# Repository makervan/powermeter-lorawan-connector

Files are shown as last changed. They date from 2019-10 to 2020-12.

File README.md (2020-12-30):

# DC Power Meter LoRaWAN Connector Node
LoRaWAN node to send data from the GC90/GC91 DC power meters via TTN. Based on an Arduino Pro Mini and the RFM95 LoRa module.

## Hardware
* Arduino Pro Mini 3.3V 8Mhz
* RFM95/96 LoRaWAN module
* [uFL socket](https://www.digikey.de/product-detail/en/linx-technologies-inc/CONUFL001-SMD-T/CONUFL001-SMD-TCT-ND/7427733) or edge mount SMA socket
* 2 BSS138 MOSFETs (Q1/Q2) and 2x 10k resistors (R3/R4, 0805) for the level shifter
* USB A socket
* 2 resistors (R1/R2, 0805) to form a voltage divider for measuring the input voltage (optional, values depending on voltage range)
* Groove connector (optional)

## Payload decoder
If you use the TTN network, you can use the following payload decoder:

```
function Decoder(bytes, port) {
  // Decode an uplink message from a buffer
  // (array) of bytes to an object of fields.
  var decoded = {};
  decoded.voltage = (bytes[2] << 8 | bytes[1]) / 100;
  decoded.current = (bytes[4] << 8 | bytes[3]) / 1000;
  decoded.usage = (bytes[8] << 24 | bytes[7] << 16 | bytes[6] << 8 | bytes[5]) / 1000;
  decoded.cum_usage = (bytes[12] << 24 | bytes[11] << 16 | bytes[10] << 8 | bytes[9]) / 1000;

  return decoded;
}
```

## License
* Hardware is based off a design by [Doug Larue](https://github.com/dlarue) with additions by me, Severin Schols. It's licensed under Creative Commons Attribution-ShareAlike 4.0 International License (CC BY-SA 4.0)
* Software (firmware and the payload decoder) are licensed under MIT License

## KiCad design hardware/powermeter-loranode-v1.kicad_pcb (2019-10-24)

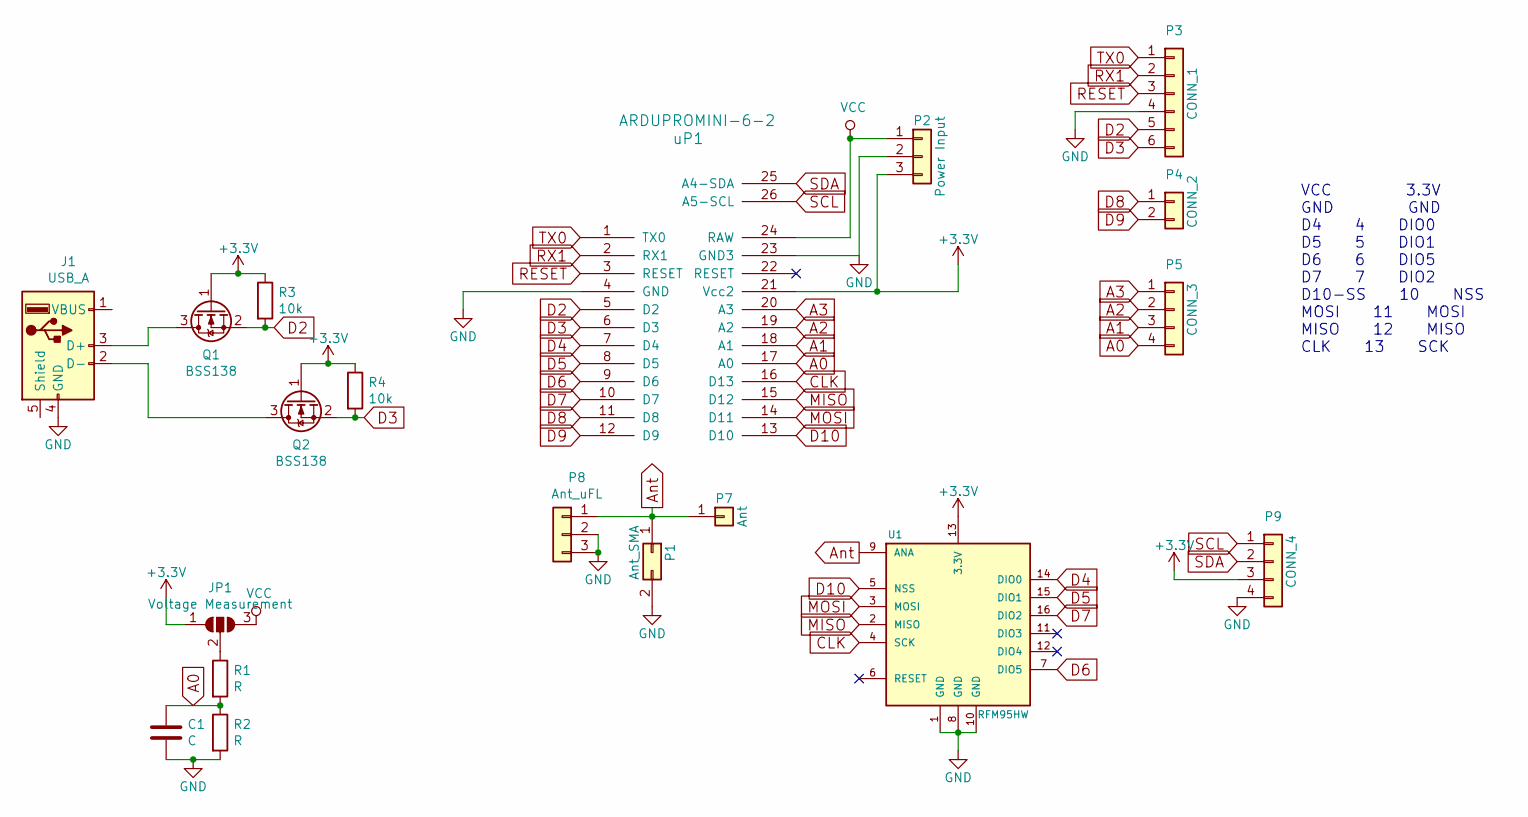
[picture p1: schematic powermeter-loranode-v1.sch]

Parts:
C1: C; C_0805_2012Metric_Pad1.15x1.40mm_HandSolder
J1: USB_A; USB_A_Stewart_SS-52100-001_Horizontal
JP1: Voltage Measurement; SolderJumper-3_P1.3mm_Open_RoundedPad1.0x1.5mm_NumberLabels
P1: Ant_SMA; SMA_EDGE
P2: Power Input; PINHEAD1-3
P3: CONN_1; Pin_Header_Straight_1x06
P4: CONN_2; Pin_Header_Straight_1x02
P5: CONN_3; Pin_Header_Straight_1x04
P7: Ant; PINTST
P8: Ant_uFL; U.FL-COAX
P9: CONN_4; NS-Tech_Grove_1x04_P2mm_Vertical
Q1, Q2: BSS138; SOT-23
R1, R2: R; R_0805_2012Metric_Pad1.15x1.40mm_HandSolder
R3, R4: 10k; R_0805_2012Metric_Pad1.15x1.40mm_HandSolder
U1: RFM95HW; RFM69HW_SMD_Handsoldering-Narrow
uP1: ARDUPROMINI-6-2; pro_mini-26

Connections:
+3V3: JP1.1 (A), P2.3, P9.3, Q1.1 (G), Q2.1 (G), R3.1, R4.1, U1.13 (3.3V), uP1.21 (Vcc2)
A0: C1.1, P5.4, R1.2, R2.1, uP1.17 (A0)
A1: P5.3, uP1.18 (A1)
A2: P5.2, uP1.19 (A2)
A3: P5.1, uP1.20 (A3)
Ant: P1.1, P7.1, P8.1, U1.9 (ANA)
CLK: U1.4 (SCK), uP1.16 (D13)
D2: P3.5, Q1.2 (S), R3.2, uP1.5 (D2)
D3: P3.6, Q2.2 (S), R4.2, uP1.6 (D3)
D4: U1.14 (DIO0), uP1.7 (D4)
D5: U1.15 (DIO1), uP1.8 (D5)
D6: U1.7 (DIO5), uP1.9 (D6)
D7: U1.16 (DIO2), uP1.10 (D7)
D8: P4.1, uP1.11 (D8)
D9: P4.2, uP1.12 (D9)
D10: U1.5 (NSS), uP1.13 (D10)
GND: C1.2, J1.4 (GND), P1.2, P2.2, P3.4, P8.2, P8.3, P9.4, R2.2, U1.1 (GND), U1.8 (GND), U1.10 (GND), uP1.4 (GND), uP1.23 (GND3)
MISO: U1.2 (MISO), uP1.15 (D12)
MOSI: U1.3 (MOSI), uP1.14 (D11)
unnamed: J1.2 (D-), Q2.3 (D)
unnamed: J1.3 (D+), Q1.3 (D)
unnamed: JP1.2 (C), R1.1
RESET: P3.3, uP1.3 (RESET)
RX1: P3.2, uP1.2 (RX1)
SCL: P9.1, uP1.26 (A5-SCL)
SDA: P9.2, uP1.25 (A4-SDA)
TX0: P3.1, uP1.1 (TX0)
VCC: JP1.3 (B), P2.1, uP1.24 (RAW)

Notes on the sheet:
VCC 3.3V GND GND D4 4 DIO0 D5 5 DIO1 D6 6 DIO5 D7 7 DIO2 D10-SS 10 NSS MOSI 11 MOSI MISO 12 MISO CLK 13 SCK

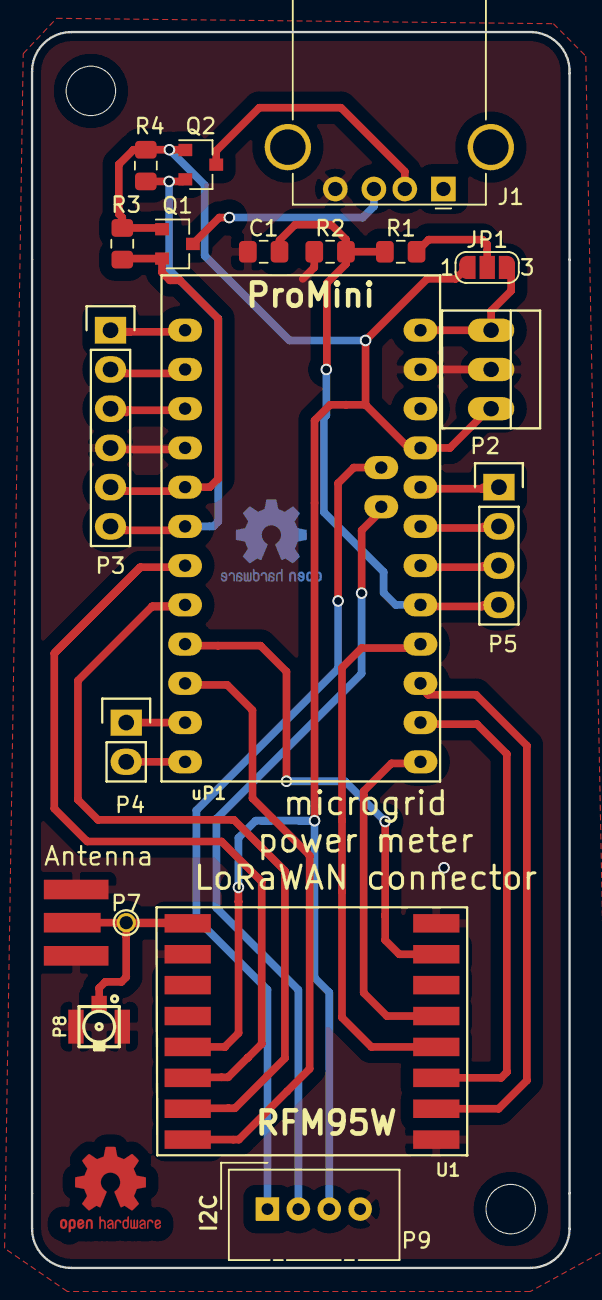
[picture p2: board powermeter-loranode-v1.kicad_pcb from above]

Board: 2 copper layers, 34.8 x 80.0 mm, 19 parts (0 on the bottom side), 28 nets.

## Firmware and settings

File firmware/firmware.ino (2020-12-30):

/*
 * DC Meter consume01
 * 
 * Data format v0:
 *  0 - version + config, for now 0x00
 *  1-2 - voltage in 0.01V, unsigned int
 *  3-4 - current in mA, unsigned int
 *  5-8 - usage in mWh, unsigned long
 *  9-12 - cummulative usage in mWh, unsigned long
 * 
 */
#include <lmic.h>
#include <hal/hal.h>
#include "config.h"

void os_getArtEui (u1_t* buf) { memcpy_P(buf, APPEUI, 8);}
void os_getDevEui (u1_t* buf) { memcpy_P(buf, DEVEUI, 8);}
void os_getDevKey (u1_t* buf) { memcpy_P(buf, APPKEY, 16);}

const unsigned TX_INTERVAL = 20;

static uint8_t mydata[20];
static osjob_t sendjob;

const lmic_pinmap lmic_pins = {
    .nss = 10,
    .rxtx = LMIC_UNUSED_PIN,
    .rst = LMIC_UNUSED_PIN, // hardwired to AtMega RESET
  .dio = {4,5,LMIC_UNUSED_PIN}//  .dio = {4, 5, LMIC_UNUSED_PIN},
};

const byte command[] = {0x77, 0x33, 0xC0, 0x41};
uint32_t voltage, current, power, usage, cum_usage;
uint16_t voltage_conv, current_conv;
uint16_t temperature;
#include <SoftwareSerial.h>

SoftwareSerial gc9x(3, 2); // RX, TX

void onEvent (ev_t ev) {
    Serial.print(os_getTime());
    Serial.print(": ");
    switch(ev) {
        case EV_SCAN_TIMEOUT:
            Serial.println(F("EV_SCAN_TIMEOUT"));
            break;
        case EV_BEACON_FOUND:
            Serial.println(F("EV_BEACON_FOUND"));
            break;
        case EV_BEACON_MISSED:
            Serial.println(F("EV_BEACON_MISSED"));
            break;
        case EV_BEACON_TRACKED:
            Serial.println(F("EV_BEACON_TRACKED"));
            break;
        case EV_JOINING:
            Serial.println(F("EV_JOINING"));
            break;
        case EV_JOINED:
            Serial.println(F("EV_JOINED"));

            // Disable link check validation (automatically enabled
            // during join, but not supported by TTN at this time).
            LMIC_setLinkCheckMode(0);
            break;
        case EV_RFU1:
            Serial.println(F("EV_RFU1"));
            break;
        case EV_JOIN_FAILED:
            Serial.println(F("EV_JOIN_FAILED"));
            break;
        case EV_REJOIN_FAILED:
            Serial.println(F("EV_REJOIN_FAILED"));
            break;
            break;
        case EV_TXCOMPLETE:
            Serial.println(F("EV_TXCOMPLETE (includes waiting for RX windows)"));
            if (LMIC.txrxFlags & TXRX_ACK)
              Serial.println(F("Received ack"));
            if (LMIC.dataLen) {
              Serial.println(F("Received "));
              Serial.println(LMIC.dataLen);
              Serial.println(F(" bytes of payload"));
            }
            /*Serial.print(F("Frequency: "));
            Serial.println(LMIC.freq);
            Serial.print(F("RSSI: "));
            Serial.println(LMIC.rssi);
            Serial.print(F("SNR: "));
            Serial.println(LMIC.snr);
            Serial.print(F("txpow: "));
            Serial.println(LMIC.txpow);*/
            Serial.print(F("adrTxPow: "));
            Serial.println(LMIC.adrTxPow);
            Serial.print(F("txChnl: "));
            Serial.println(LMIC.txChnl);
            Serial.println();
            // Schedule next transmission
            os_setTimedCallback(&sendjob, os_getTime()+sec2osticks(TX_INTERVAL), do_send);
            break;
        case EV_LOST_TSYNC:
            Serial.println(F("EV_LOST_TSYNC"));
            break;
        case EV_RESET:
            Serial.println(F("EV_RESET"));
            break;
        case EV_RXCOMPLETE:
            // data received in ping slot
            Serial.println(F("EV_RXCOMPLETE"));
            break;
        case EV_LINK_DEAD:
            Serial.println(F("EV_LINK_DEAD"));
            break;
        case EV_LINK_ALIVE:
            Serial.println(F("EV_LINK_ALIVE"));
            break;
         default:
            Serial.println(F("Unknown event"));
            break;
    }
}

void do_send(osjob_t* j){
    // Check if there is not a current TX/RX job running
    if (LMIC.opmode & OP_TXRXPEND) {
        Serial.println(F("OP_TXRXPEND, not sending"));
    } else {
      gatherData();
      printData();

      voltage_conv = (unsigned int)(voltage / 10.0);
      current_conv = (unsigned int)current;

      mydata[0] = 0b00000000;
      memcpy(mydata + 1, &voltage_conv, sizeof(voltage_conv));
      memcpy(mydata + 1 + sizeof(voltage_conv), &current_conv, sizeof(current_conv));
      memcpy(mydata + 1 + sizeof(voltage_conv) + sizeof(current_conv), &usage, sizeof(usage));
      memcpy(mydata + 1 + sizeof(voltage_conv) + sizeof(current_conv) + sizeof(usage), &cum_usage, sizeof(cum_usage));

        // Prepare upstream data transmission at the next possible time.
        LMIC_setTxData2(1, mydata, 16, 0);
        Serial.println(F("Packet queued"));
    }
    // Next TX is scheduled after TX_COMPLETE event.
}


void setup() {
    Serial.begin(9600);
    Serial.println(F("DC Meter Reader"));
  gc9x.begin(19200);
    // LMIC init
    os_init();

    // Reset the MAC state. Session and pending data transfers will be discarded.
    LMIC_reset();

    // Let LMIC compensate for +/- 1% clock error
    LMIC_setClockError(MAX_CLOCK_ERROR * 1 / 100);

    // Start job (sending automatically starts OTAA too)
    do_send(&sendjob);
}

void loop() {
    os_runloop_once();
}


uint8_t readWhenAvailable() {
  while (gc9x.available() == 0) {
    delay(10);
  }
  return gc9x.read();
}

void gatherData() {
  uint8_t a,b,c,d;
  gc9x.write(command,4);
  // Header
  readWhenAvailable();
  readWhenAvailable();
  readWhenAvailable();
  readWhenAvailable();
  // address
  readWhenAvailable();
  // voltage
  a = readWhenAvailable();
  b = readWhenAvailable();
  c = readWhenAvailable();
  d = readWhenAvailable();
  voltage = (long)a << 24 |  (long)b << 16 |  (long)c << 8 | d;
  // current
  a = readWhenAvailable();
  b = readWhenAvailable();
  c = readWhenAvailable();
  d = readWhenAvailable();
  current = (long)a << 24 |  (long)b << 16 |  (long)c << 8 | d;
  // power
  a = readWhenAvailable();
  b = readWhenAvailable();
  c = readWhenAvailable();
  d = readWhenAvailable();
  power = (long)a << 24 |  (long)b << 16 |  (long)c << 8 | d;
  // usage
  a = readWhenAvailable();
  b = readWhenAvailable();
  c = readWhenAvailable();
  d = readWhenAvailable();
  usage = (long)a << 24 |  (long)b << 16 |  (long)c << 8 | d;
  // loadtime
  readWhenAvailable();
  readWhenAvailable();
  readWhenAvailable();
  readWhenAvailable();
  // capacity
  readWhenAvailable();
  readWhenAvailable();
  readWhenAvailable();
  readWhenAvailable();
  // cummulative usage
  a = readWhenAvailable();
  b = readWhenAvailable();
  c = readWhenAvailable();
  d = readWhenAvailable();
  cum_usage = (long)a << 24 |  (long)b << 16 |  (long)c << 8 | d;
  // cum. capacity
  readWhenAvailable();
  readWhenAvailable();
  readWhenAvailable();
  readWhenAvailable();
  // cum. loadtime
  readWhenAvailable();
  readWhenAvailable();
  readWhenAvailable();
  readWhenAvailable();
  // temperature
  c = readWhenAvailable();
  d = readWhenAvailable();
  temperature = (c << 8) + d;
  // switch
  readWhenAvailable();
}

void printData() {
  Serial.print("Voltage: ");
  Serial.print(voltage);
  Serial.println(" mV");
  Serial.print("Current: ");
  Serial.print(current);
  Serial.println(" mA");
  Serial.print("Power: ");
  Serial.print(power);
  Serial.println(" mW");
  Serial.print("Usage: ");
  Serial.print(usage);
  Serial.println(" mWH");
  Serial.print("Cumulative Usage: ");
  Serial.print(cum_usage);
  Serial.println(" mWH");
  Serial.print("Temperature: ");
  Serial.print(temperature/10.0);
  Serial.println(" °C");

  Serial.println("-----------------------------");
}
